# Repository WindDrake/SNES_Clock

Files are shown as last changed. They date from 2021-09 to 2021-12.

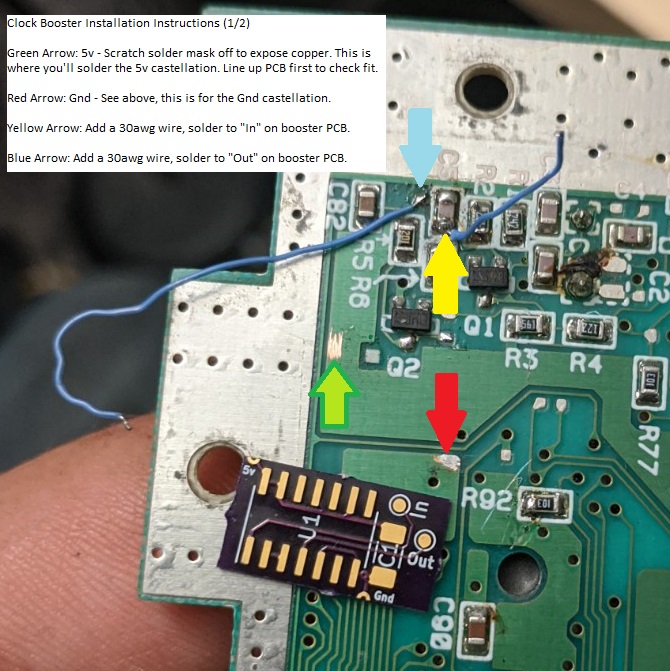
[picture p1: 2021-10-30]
clock_booster_step_1.jpg

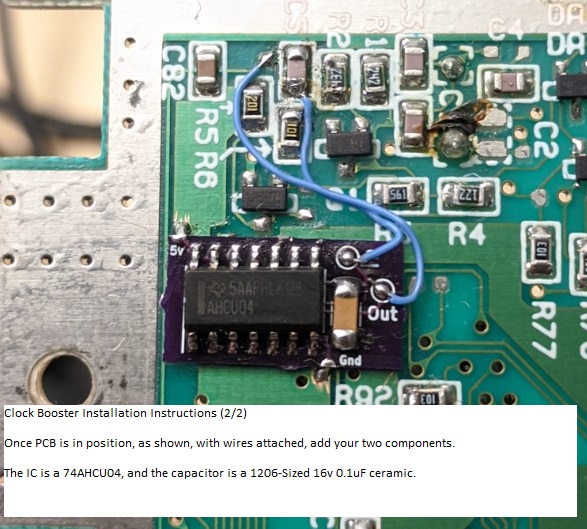
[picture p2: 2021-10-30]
clock_booster_step_2.jpg

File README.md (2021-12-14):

# SNES_Clock
 Nintendo SNES SHVC-CPU-01 Clock Buffer

 Design done in Kicad 5.1.10 with Digikey libraries. If you want to edit it, you'll need those libraries as well as these files.

 The purpose of this board is to fix FXPak/SD2SNES issues with SHVC-CPU-01-based SNES consoles. The original clock driver on these PCB's is extremely load sensitive.
 
 Tested working, this workaround solves the glitches with the aforementioned cart(s).

 Installation instructions done, along with a pre and post-mod MCK trace waveform image. (10/30/21)
 
 Forgot to note - you'll want to have these made as the 2oz/0.8mm PCB's if using OshPark, so the castellations come out correctly.
 https://oshpark.com/shared_projects/jDfGjfv4 - Direct shared link @ OshPark

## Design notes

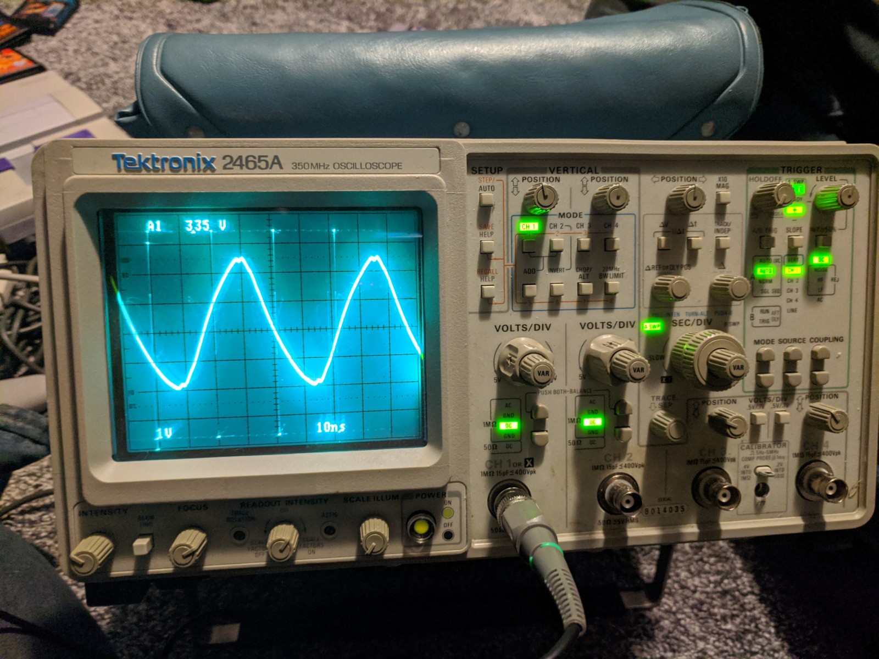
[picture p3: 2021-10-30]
Boosted MCK Trace.jpg

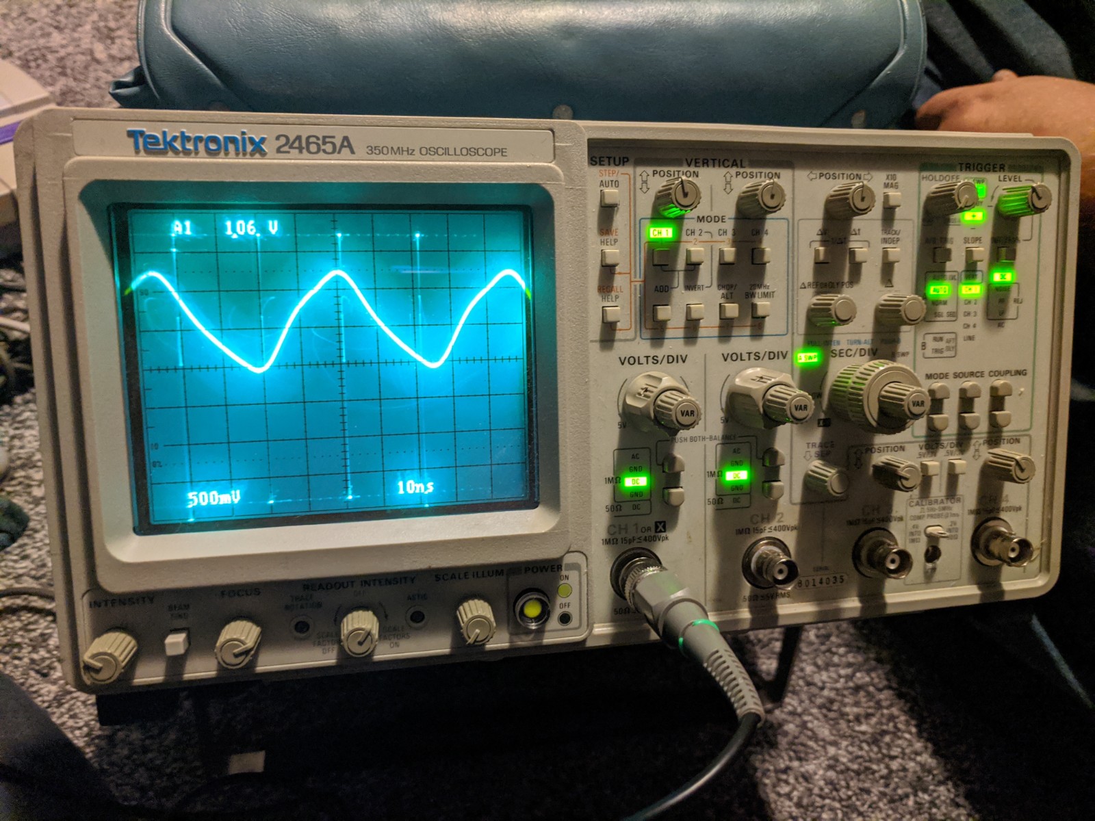
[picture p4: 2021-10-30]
Original MCK Trace.jpg

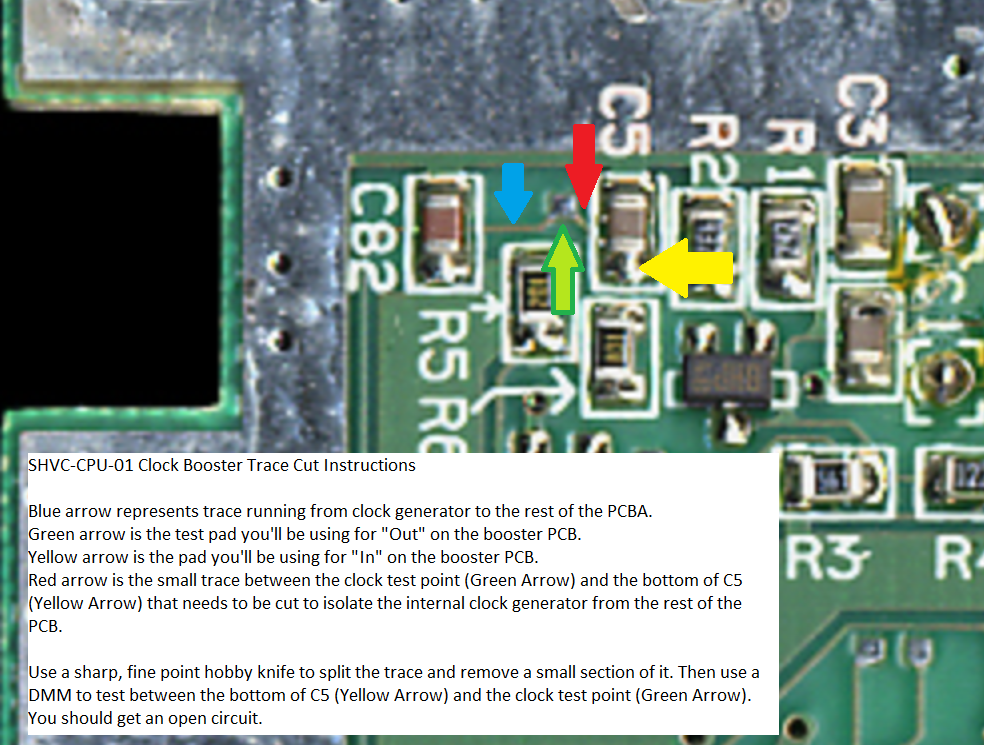
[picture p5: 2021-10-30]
clock_booster_trace_cut.png

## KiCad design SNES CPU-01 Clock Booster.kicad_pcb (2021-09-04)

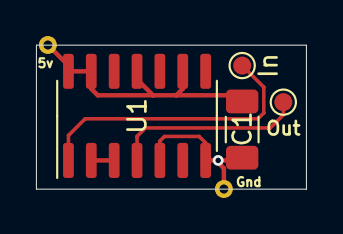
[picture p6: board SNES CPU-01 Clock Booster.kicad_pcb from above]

Board: 2 copper layers, 15.0 x 8.0 mm, 6 parts (0 on the bottom side), 5 nets.

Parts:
5v: 5vPad; 1mm_PTH
C1: 0.1uF; C_1206_3216Metric_Pad1.33x1.80mm_HandSolder
Gnd: GndPad; 1mm_PTH
In: ClockInPad; TestPoint_Pad_D1.0mm
Out: ClockOutPad; TestPoint_Pad_D1.0mm
U1: 74AHCU04; SOIC-14_3.9x8.7mm_P1.27mm

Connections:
+5V: 5v.1, C1.1, U1.9, U1.11, U1.13, U1.14
GND: C1.2, Gnd.1, U1.5, U1.7
unnamed: In.1, U1.1
unnamed: Out.1, U1.4
unnamed: U1.2, U1.3
